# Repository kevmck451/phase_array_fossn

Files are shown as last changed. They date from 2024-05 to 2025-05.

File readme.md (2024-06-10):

# Forward Operations Security Sensor Network (FOSSN)

## Project Overview

What they want from us:
	- easily deployable networked sensor system is needed to provide automated security monitoring
	- develop concepts for a Forward Operations Sensor Network

The sensor system should 
	- detect encroaching personnel and vehicles (ground and aerial)
	- presence of chemical, biological, radiological, and nuclear (CBRN) materials
	- system of unattended sensors will communicate via a network
	- Autonomous algorithms will consolidate sensor inputs and provide summary notifications of activity within the area monitored to personnel in the FO unit

Results of this study:
	- a demonstration of several key technologies necessary for building an effective FOSSN 
	- a detailed plan for the full development of the FOSSN

Complementary sensors of acoustic

Unattended Ground Sensors (UGS)
Memphis has developed the means for implementing acoustic, magnetic, and hyperspectral sensors for UAS that can be translated to UGS sensing

The FOSSN team will translate these wide area coverage sensors into an UGS configuration and will demonstrate a VIS and LWIR capability for wide area coverage to include the detection and recognition of humans and vehicles.  The FOSSN team will also perform field experimentation to determine the performance of these systems in the range at which these systems effectively engage humans and military vehicles, including threat UAS.

The FOSSN team will also leverage existing phased array acoustic sensing to a UGS configuration

All sensors will be tied together leveraging Named Data Networking (NDN) and multi-hop ad hoc communications developed for the ARL program

Based on prior experience and input from task 3.1, research areas needed for the development of a complete and operationally effective system will be developed. For each area, recommendations regarding technical approaches will be made and a report produced. 

3.4.2 Phased Array Acoustic Sensor Research
	- The FOSSN team will develop a wide area coverage acoustic with at least a 180 degree FOV with resolution sufficient to localize a target direction when combined with other sensing modalities. This sensor will leverage technologies developed for the UAS based acoustic interrogator mission.
	- The FOSSN team will demonstrate the acoustic UGS systems in the field.  The system will be demonstrated in the field with a ground sensor coupled to a tabletop computer that can show the performance of the system.
	- The FOSSN team will determine the performance of the wide area acoustic system.  A theoretical performance will be provided as well as a field experiment/demonstration that provides the range at which aerial and ground vehicles can be detected and recognized.

The FOSSN team will develop an overall plan for developing a system that meets the needs of field artillery security. This plan will detail any needed technology development and the necessary resources to execute the plan. 

Test and Evaluation (T&E) Plan – Based on the results of laboratory and field evaluations and demonstrations, an overall T&E plan will be developed for a complete field artillery security system. 

# Repo Contents

## I. Beamform

## II. Circuit Boards

### 1. DE10_Shield

### 2. Mic_Antenna

## III. Documents

## IV. FPGA SoC Setup

1. Creating a NixOS for an FPGA SoC
2. Initial Build for SD Card Image
3. Initial Installation on DE10
4. Developing Application and Maintenance

### 1. FPGA Folder

- The Altera DE10 Nano uses Quartus to synthesize/place & route the HDL code to the FPGA 
- Quartus is only able to do this using an intel processor
- Nix is linux
- so in order to develop software on this device with Nix, a computer with intel processor and linux is needed

### 2. Nix
- Development Environment
- Package Management
- FPGA Interaction Tool Chain

### 3. Design

### 4. Docs

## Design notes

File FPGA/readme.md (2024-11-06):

# <u>Setup and Maintenance for the DE10-Nano</u>

**<u>First Time Setup Instructions</u>**
1. Programming Environment Setup
2. Building SD Card Image
3. First Connection to DE10-Nano

**<u>Developing and Maintenance</u>**
1. Updating OS Packages
2. Library update maintenance
3. Rebuilding software changes

---
# <u>First Time Setup Instructions</u>
- Building the necessary files for operating the DE10 Nano must be done with:
  - a pc with an intel processor running linux
  - Ubuntu is recommended, but other variants like lubuntu can work
  - lubuntu is lite ubuntu which is for computers with limited cpu ability
- This process was tested on a [Wo-We Mini PC](https://www.amazon.com/dp/B0CLD8JRWK?psc=1&ref=ppx_yo2ov_dt_b_product_details)
  - it worked but was very slow and needed special consideration with some aspects of the nix builds 
  - It's processor is an Intel Celeron N4020 CPU @ 1.1GHz x 2 (4GB RAM) running [lubuntu 24.04 64 bit](https://lubuntu.me/downloads/)
- It was also test with a [GMKtec Mini PC](https://www.amazon.com/gp/product/B0B75PT2RY/ref=ppx_yo_dt_b_search_asin_title?ie=UTF8&th=1)
  - processor is an Intel 11th Gen N5105 @ 3.4GHz x 4 (8GB RAM) running [Ubuntu 20.04.6](https://releases.ubuntu.com/focal/)

---
## <u>1. Programming Environment Setup</u>

### 1.1: Computer Requirements
- recommended minimum computer requirements
  - having two cores and 4GB memory with swap memory at 16GB is theoretically possible
  - four cores with 8GB memory and 16GB swap memory took 10+hrs to build for the first time

---
### 1.2: Installing Necessary Libraries
- htop: used to monitor computer during builds
```zsh
sudo apt install htop
```
- git: updating code repository after changes
```zsh
sudo apt install git
```
- wormhole: easily transfer files over the network without needing an IP
```zsh
sudo apt install magic-wormhole
```
- curl: used to install nix / copies files from a url
```zsh
sudo apt install curl
```
- nix: environment shells / NixOS builds / etc
```zsh
sudo apt install nixos
```
- ifconfig: used to see device's network information (specifically IP address)
```zsh
sudo apt install net-tools
```
- ssh: allows you to "login" to other computers and control them from the terminal
```zsh
sudo apt install openssh-server
```
- zstd: for decompressing .zst files
```zsh
sudo apt install zstd
```
- minicom: used to communicate with devices through UART
```zsh
sudo apt install minicom
```
- Sometimes, you might need appropriate permissions to access these devices
- You can change the permissions by adding your user to the dialout group
- kevmck would be replaced with your username
```zsh
sudo usermod -aG dialout kevmck
```
- program that tries to find modems on serials ports so get rid of it
```zsh
sudo apt purge modemmanager
```
This process is actually a perfect segway into NixOS in that in order to set up Ubuntu OS to do what you need.
This process has to be done every time a new computer is set up. That can be kind of cumbersome.
What if there was an OS that you could declare everything you need up front and then build/rebuild when changes are made.
Although Nix has many features, this is main advantage of using nix that you can declare everything you need
and you know that it will be built the same way everytime and will always work exactly the way it's suppose to

---
### 1.3: Installing Nix 
- [Nix Website](https://nixos.org/download/#nixos-iso)
- Browsing for Nix Packages [Package Search Website](https://search.nixos.org/packages?ref=itsfoss.com) 
- Multi-user installation for Linux
```zsh
sh <(curl -L https://nixos.org/nix/install) --daemon
```
- Adding the flake feature
- the folder might already exist
```zsh
sudo mkdir /etc/nixos
sudo nano /etc/nixos/nixos.conf
```
- Add this to the config file
- the first line is most important
- if there's something already there, delete it
~~~
# Nix Config File

# enable flake feature
experimental-features = nix-command flakes

# specifies which users are trusted by the Nix daemon
trusted-users = @root

# automatically optimize the store by deduplicating files
# performing other optimizations to reduce disk usage and improve performance
auto-optimise-store = true
~~~

---
### 1.4: Increasing Swap Memory
What is Swap Memory and why it's important
- check current swap memory size with htop or this;
```zsh
sudo swapon --show
```
- disable current swap file temporarily
```zsh
sudo swapoff /swapfile
```
- resize the swap file to 16GB
```zsh
sudo dd if=/dev/zero of=/swapfile bs=1M count=16384
```
- set the correct permissions
```zsh
sudo chmod 600 /swapfile
```
- setup the swap area
```zsh
sudo mkswap /swapfile
```
- enable the swap file
```zsh
sudo swapon /swapfile
```
- you should see the swap changing in htop but can also check with this:
```zsh
sudo swapon --show
```
- Edit the '/etc/fstab' file to ensure the swap file is used at boot
```zsh
sudo nano /etc/fstab
```
- add or update the following line to ensure it reads:
~~~
/swapfile none swap sw 0 0
~~~

---
## <u>2. Building SD Card Image</u>

### 2.1: Build SD Card Image for DE10
- This repo contains an already made NixOS system for the DE10
```zsh
git clone https://github.com/kevmck451/phase_array_fossn.git 
```
```zsh
cd phase_array_fossn/FPGA
```
- this only needs to be done once
- then updates can be run from the device itself with ```nix rebuild``` command

- run the command:
```zsh
nix build .#nixosConfigurations.de10-nano -L
```
- add the -j1 flag if using small cpu computers (1 job built at a time)
- -L is to see a verbose output as it builds
- this will take some time the first time (8+ hours potentially)
- there is no harm in stopping the build and restarting it
- it could potentially reduce memory if needed
- might run into 'lack of disk space' error
  - this might be due to tmp space not big enough
  - google remount /tmp with larger size
---

### 2.2: Create Bootable Drive
- this part could be done on any computer
- the ```nix build``` command from above makes a folder called "result"
- inside that folder is sd-image folder
- inside that is a .img.zst file
- use zstdcat & dd to decompress the image and write it to the SD card

1. Insert SD card into computer
2. Identify sd card's device name
   - not the mount point of the SD card, but the device name
```zsh
lsblk 
```
   - the name that corresponds with the mount point / SD card name
   - mine is 'mmcblk1'

3. Unmount the SD card (if it's mounted)
   - it wont hurt to do this if you're not sure
```zsh
sudo umount /dev/mmcblk1
```
4. Decompress and Write Image
   - *Warning:* incorrect use of ```dd``` commands could destroy your computer's internal disk, so use with care

```zsh
zstdcat result/sd-image/*.img.zst | sudo dd of=/dev/mmcblk1 bs=4M status=progress conv=fsync
```
- if you eject the sd card when it's done and reinsert it, it should say NixOS as the sd card name

---
## <u>3. First Connection to DE10-Nano</u>

### 3.1: Starting up the DE10
- put the SD card in the DE10
- set de10 mel switches to all 0 (up)
- connect to the de10 through the UART mini usb connector
- plug the power cable to the DE10

There are two ways we will connect to the DE10:
1. connection over UART 
2. connection via ssh with ethernet over usb 
    
---

#### 3.2: UART Connection on Linux
- plug in the mini-usb cable into the UART connector (by the ethernet port)
- the LEDs should light up immediately because it's getting power over the usb cable
  - even if the board is off
- start the UART connection
- most likely USB0, but maybe USB1
```zsh
minicom -D /dev/ttyUSB0 -b 115200
```
- once run, you should see start up of device
- to exit session: press control a, let go of both, press x

---

#### 3.3: SSH Connection
- plug in the micro-usb cable into the board
- connection to the internet is required
- SSH into FPGA
```zsh
ssh nixos@192.168.80.1
```
- save the address to your computer (optional)
```zsh
sudo nano /etc/hosts 
```
- add to the file
~~~
# DE10 Nano FPGA
192.168.80.1 fpga
~~~
- now you can ssh into it with this command
```zsh
ssh nixos@fpga 
```

#### 3.4: SSH Connection with MacBook
- this is done on the MacBook terminal
- get intel linux ip address and username
- Copy SSH key to connect without password
- replace kevmck with your username
- replace that IP address with your linux computer's
```zsh
ssh-copy-id kevmck@141.225.162.254
```
- SSH into intel linx comp
```zsh
ssh kevmck@141.225.162.254
```
- SSH into FPGA from MacBook with jumping
```zsh
ssh nixos@192.168.80.1 -J kevmck@141.225.162.254    
```

---
### 3.5 Test FPGA wavdump functionality
- on macbook, ssh into fpga with jumping (from 5.3)
- run the wavdump command with -f for fake mics
- run with -r for raw output, not convolved
```zsh
sudo wavdump -f -r fake_mic_test.wav
```
- once a few samples have been generated, press ctl c to stop

- copy the file to macbook for inspection with Audacity
```zsh
scp -J kevmck@141.225.162.254 nixos@192.168.80.1:/home/nixos/fake_mic_test.wav .
```
- from here, changes made to code will need to be rebuilt

---
# <u>Developing and Maintenance</u>
## <u>1. Updating OS Packages</u>

### 1.1: Adding Shell Libraries
- find packages in 'nixos/sd-image/default.nix'
- when changes are made, follow process in 3. Rebuilding Software Changes to implement

### 1.2: Adding Python Libraries

---
## <u>2. Library Update Maintenance</u>

---
## <u>3. Rebuilding Software Changes</u>

- if using MacBook to control headless Intel Linux PC then ssh into intel linux pc
```zsh
ssh kevmck@141.225.167.131
```
- from here you can either do this from the intel linux comp or ssh'd from macbook
- cd into FPGA folder with nix flake file
```zsh
cd Desktop/phase_array_fossn/FPGA
```
- update the changes that were made to the intel linux pc
```zsh
git pull
```
- cd into FPGA folder
- get inside a nix shell to rebuild any changes
```zsh
nix develop --profile profiles/dev
```
- note: if using a dash (nix-develop) nix would expect a default.nix file
  - not using the dash, signifies using a nix.flake file
- for significant changes, it's best use the boot flag
```zsh
nixos-rebuild --target-host nixos@192.168.80.1 --fast --use-remote-sudo --flake .#de10-nano boot -L 
```
- otherwise the switch command is fine
```zsh
nixos-rebuild --target-host nixos@192.168.80.1 --fast --use-remote-sudo --flake .#de10-nano switch -L 
```

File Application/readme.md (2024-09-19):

# App Info

## Powering On
- when the phased array is powered on, computer cannot be connected to it
- once booted, connect computer via ethernet and run Application.main

## Monitoring the FPGA and Pi during run
```zsh
ssh admin@192.168.1.1 
journalctl -fu temp-sensor-server
```

```zsh
ssh nixos@192.168.1.201
journalctl -fu start-mic-server
```

- if pi is plugged campus ethernet and wifi is connected on laptop
```zsh
ssh admin@pi-nix.uom.memphis.edu   
```

```zsh
sudo nano /etc/resolv.conf
```
~~~
nameserver 8.8.8.8
~~~

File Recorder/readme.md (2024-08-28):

# Controller

## Audio Receiver
- The `AudioReceiver` class is designed to collect RAW audio data from an FPGA server
- It connects to the server over a socket, receives audio data in chunks, and stores it in a queue for processing
- This implementation is intended to handle multi-channel audio data in real-time
- Connects to an FPGA server using a socket
- Receives audio data in real-time
- Supports multi-channel audio data
- Stores received audio data in a thread-safe queue
- Provides a method to retrieve audio data for processing

```zsh
journalctl -fu start-mic-server
```

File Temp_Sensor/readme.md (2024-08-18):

# Temp Sensor: BME280

## Physical Connection
- Using 4 pin 1/8" audio jack for connector (TRRS)
4: tip: 3.3V
3: ring 1: scl
2: ring 2: gnd
1: sleeve: sda

#### confirming the address  
```zsh
# nix environment 
nix-shell -p i2c-tools

# read buses
i2cdetect 0
i2cdetect 1
i2cdetect 2
i2cdetect 3
i2cdetect 4
```
- 3 was the only one with a single address at 76
~~~
     0  1  2  3  4  5  6  7  8  9  a  b  c  d  e  f
00:                         -- -- -- -- -- -- -- -- 
10: -- -- -- -- -- -- -- -- -- -- -- -- -- -- -- -- 
20: -- -- -- -- -- -- -- -- -- -- -- -- -- -- -- -- 
30: -- -- -- -- -- -- -- -- -- -- -- -- -- -- -- -- 
40: -- -- -- -- -- -- -- -- -- -- -- -- -- -- -- -- 
50: -- -- -- -- -- -- -- -- -- -- -- -- -- -- -- -- 
60: -- -- -- -- -- -- -- -- -- -- -- -- -- -- -- -- 
70: -- -- -- -- -- -- 76 --    
~~~

#### test script
- python console to run example script from [Github](https://projects.raspberrypi.org/en/projects/build-your-own-weather-station/2)

#### Get all libraries into nix so it can build them for access in scripts
https://github.com/rm-hull/bme280
https://github.com/rm-hull/bme280/tags

#### add script to automatic start up with Nix

- check output of print statements
```zsh
journalctl -fu temp-sensor
```
```zsh
journalctl -fu temp-sensor-server
```

#### gitpull 
```zsh
sudo -s
sudo nano /etc/resolv.conf
```
~~~
change nameserver = 8.8.8.8
~~~

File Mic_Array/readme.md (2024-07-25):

# Mic Array

2. mic_coordinates
3. time delays
   - directional cosines
   - speed of sound
   - calculate time delays
   - convert to sample delay
4. fir_filter
   - generate sinc function
   - window function
5. Convolution
6. Summation
7. Normalization

Beamforming Process:

## Microphone Array Grid:
 * Define the positions of the microphones in the array using an (x,y) coordinate system.
 * these grid coordinate are from the perspective of in front the array with (0,0) at the top left
 * the reference is from the center of the array

## Calculate Time Delays:
 * Use directional cosines to model the direction of arrival of the sound wave, assuming far-field conditions where the wavefronts are planar
 * For each microphone, calculate the time delay τi  based on the directional cosines and the positions of the microphones
 * This involves computing the path differences and converting them into time delays using the speed of sound
 * speed of sound changes depending on temperature
 * convert the time delay to sample delay by multiplying by sample rate
 * Since the calculated sample delays are not always integers, fractional delays need to be handled.
 * The most accurate way to implement fractional delays is by designing FIR filters that approximate these delays.

## Create FIR Filters:
 * For each microphone, create a sinc function centered at the delay di
 * The sinc function represents the ideal low-pass filter that will be used to create the FIR filter
 * set cutoff frequency higher than desired frequency range of interest
 * The sinc function sinc(t−di) where t is the time index and di is the delay.
 * Apply a window function (e.g., Hamming, Hann, blackman) to the sinc function to truncate it to a finite length and smooth the edges.
 * blackman provides better side lob suppression at the cost of main lobe resolution
 * increasing the number of taps can increase main lob resolution at the cost of computational complexity
 * The result is a set of FIR filter coefficients for each microphone.

## Convolution:
 * Convolve each microphone's input signal with its corresponding FIR filter coefficients.
 * Convolution is a process where the input signal is multiplied and summed with the FIR filter coefficients to produce a delayed output signal.

## Summation:
 * Sum the delayed signals from all microphones.
 * This summation aligns the signals from the desired direction (beamforming), enhancing them while attenuating signals from other directions.

## Normalization:
 * Bring values back into expected ranges

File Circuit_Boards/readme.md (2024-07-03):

# Circuit Board Information

---
## Using Mics with Antennas
- the mic symbol on the mic modules should be facing away from center when connected
- before soldering mic pins to modules, check that the INMP441 chip is correctly placed from factory
    - discard any that are not correctly aligned

---
## Ethernet Cable Configuration
- RJ45 Ethernet connectors and cabling are used to connect the microphone antennas to the fpga shield
- making the cables from scratch allowed for exact cable lengths
- the antennas were designed to optimize the configuration of the mic module pins
- in the initial testing phase, the standard TIA 568B coloring configuration was used
- this caused issues with certain data channels due to the twisted pair configuration
- the ethernet cables were reconfigured to fix this issue
- if you wanted to use standard ethernet cables, you will need to reroute the mic antenna pins
- and reassign the fpga shield pins as well

### Standard Ethernet Configuration
~~~
Twisted Pairs
- Orange Stripe: ws
- Orange: d3 <--- This channel is corrupted because of ws

- Green Stripe: d1
- Green: gnd

- Blue Stripe: d2
- Blue: pwr

- Brown Stripe: clk
- Brown: d4 <--- This channel is corrupted because of clk
~~~

### Custom Ethernet Configuration
~~~
Twisted Pairs
- Orange Stripe: ws
- Orange: pwr

- Green Stripe: d3
- Green: d1

- Blue Stripe: clk
- Blue: gnd

- Brown Stripe: d2
- Brown: d4
~~~

#### Top

| Orange Stripe | Green | Brown Stripe | Blue Stripe |
|---|---|---|---|

#### Bottom

| Green Stripe | Orange | Blue | Brown |
|---|---|---|---|

#### Left to Right
| ws  | d3  | d1  | pwr | d2  | gnd | clk | d4  |
|-----|-----|-----|-----|-----|-----|-----|-----|
| os  | gs  | g | o | brs | b | bs  | br  |

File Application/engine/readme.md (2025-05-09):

# Engine Pipeline

## Array
1. Array Configs: info specific to each array selected at runtime
2. AudioReceiver: connects to FPGA server to collect data
3. AudioStream: saves to data to disk and divides in user defined chunks for queue
4. AudioStreamSimulator: simulated stream from already collected array data

## Beamform
1. Beamform: facilities beamforming data from a given array
2. Mic_Coordinates: generates an arbitrary coordinate system for the array
3. Generate FIR Coeffs: time delays and FIR filters
4. Time Delays: calculate the time delays
5. FIR Filter: create the fir filter coefficients for each mic

## Filters
1. Processor: implements the processing pipeline for narrow band monitoring
2. High Pass: remove low frequencies below a cutoff
3. Down Sample: lower data size and low pass filter below cutoff(nyquist) / 2 
4. Normalize: min/max normalization - re-adjust data to fit inside the contain
5. Noise Reduction: possibility for noise reduction. not currently used

## Detectors
1. PCA Calculator: calculates the principal components from audio data using 'nperseg' and 'num'
2. Detectors: using pca data, a normal operation baseline is calculated and then new data is statistically compared for anomaly detection

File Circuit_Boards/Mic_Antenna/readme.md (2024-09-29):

# Mic Antenna Circuit Board in KiCad

## Front
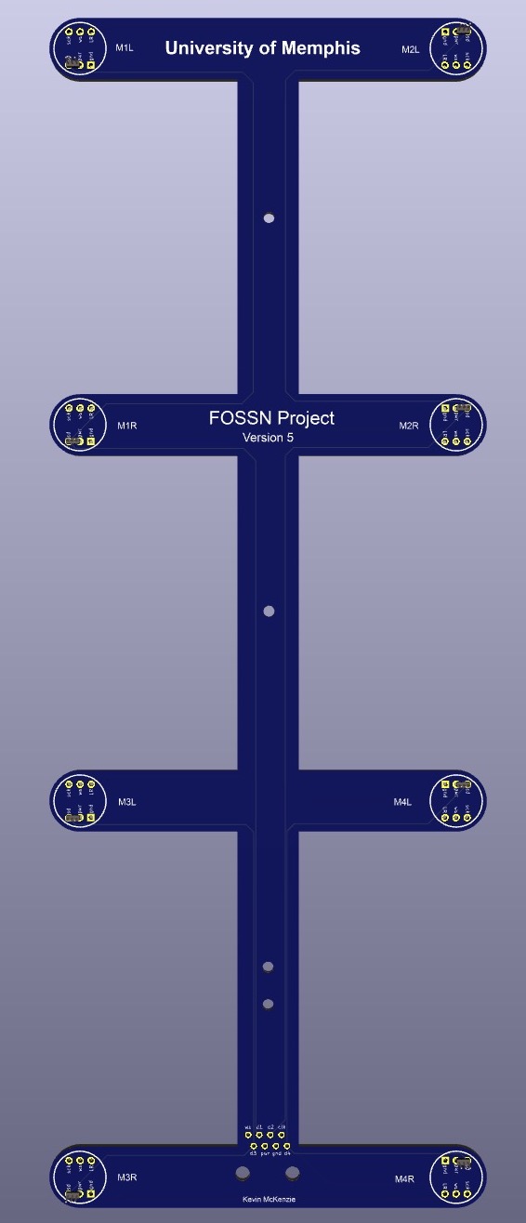
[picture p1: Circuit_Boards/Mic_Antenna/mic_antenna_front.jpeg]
Sheild Front


## Back
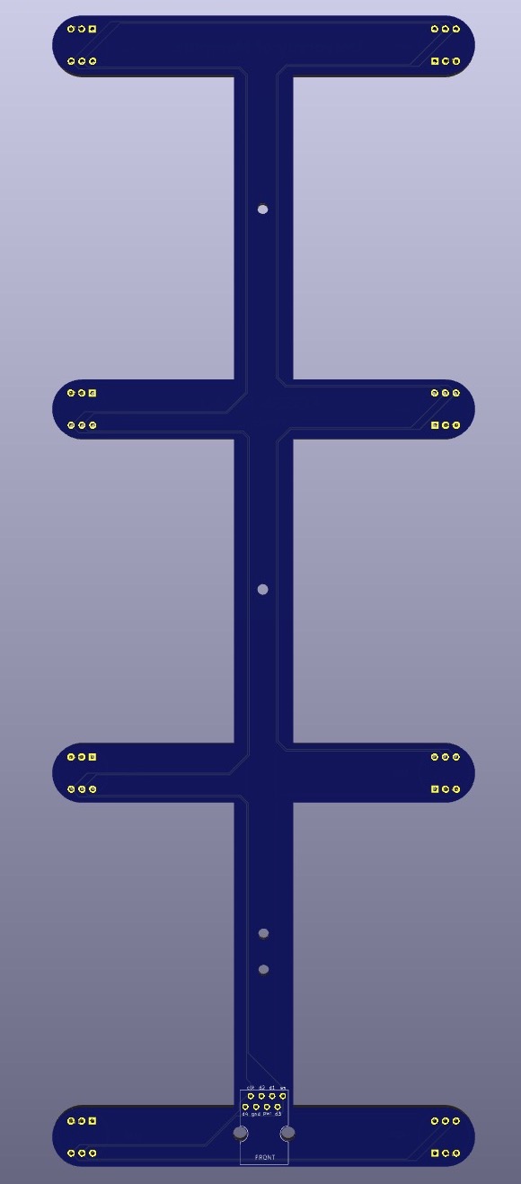
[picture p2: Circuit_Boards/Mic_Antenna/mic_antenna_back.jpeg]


## Exoskeleton
 - https://sendcutsend.com/
 - exoskeleton.stp
 - anodized aluminum (black)
 - these caused electrical interference in some mics
   - fixed by putting a sheet of printing paper in between
   - 2mm standoff screws used

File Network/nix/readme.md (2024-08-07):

# Loading and Building Networking NixOS for Raspberry Pi

## On the Raspberry Pi
- install a premade version of nix for pi
- [Tutorial](https://mtlynch.io/nixos-pi4/)

```zsh
sudo nix-channel --update
nix-env -iA nixos.git
```
- [YouTube Tutorial](https://www.youtube.com/watch?v=VIuPRL6Ucgk&list=WL&index=4)
```zsh
git clone https://github.com/kevmck451/phase_array_fossn.git
```
```zsh
cd phase_array_fossn/Network/nix/pi_sdcard
```
```zsh
sudo nix build --extra-experimental-features nix-command --extra-experimental-features flakes .#packages.aarch64-linux.sdcard
```

## On Mac
```zsh
scp nixos@192.168.0.137:~/phase_array_fossn/Network/nix/pi_sdcard/flake.lock ~/Downloads/
```
```zsh
scp -r nixos@192.168.0.137:~/phase_array_fossn/Network/nix/pi_sdcard/result ~/Downloads/
```
- remove sd card from pi and flash with new sd card image
```zsh
cd phase_array_fossn/Network/nix/pi_sdcard
```
```zsh
zstd -d result/sd-image/*.img.zst -o ~/Downloads/extracted_image.img        
```
- use belena etcher to flash to sd card
- put back in pi and start up
- find pi's ip address from router
- ssh into nixos pi
```zsh
ssh admin@192.168.0.137    
```
- enter password
- switch to root user
```zsh
sudo -s
```
```zsh
nix-channel --update
```
```zsh
nixos-generate-config
```
```zsh
nano /etc/nixos/configuration.nix
```
- everything is in the pi_config.nix file
```zsh
passwd admin
```
- choose password: nix
```zsh
nixos-rebuild switch
```
```zsh
arp -a   
```
- after disconnection from ssh, i had to unplug pi and plug back in
```zsh
arp -a   
```
- ssh into pi
```zsh
ssh admin@192.168.0.137
```
```zsh
git clone https://github.com/kevmck451/phase_array_fossn.git
```
```zsh
cd /home/admin/phase_array_fossn
git pull origin main
sudo cp /home/admin/phase_array_fossn/Network/nix/pi_config.nix /etc/nixos/configuration.nix
sudo nixos-rebuild switch
```

```zsh

```

```zsh

```

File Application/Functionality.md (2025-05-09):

# Application

1. Controller 
2. Engine 
3. GUI 
4. Temp Sensor

## Localization
    - Monitoring of each channel (current view)
    - heatmap of anomalies or energy

## Classification

## Human Operator
    - inject channel data into headphones (full range)
    - different listening modes
    - parameters to change volume or frequency

maybe have a speaker out in front of the array that can be triggered between tests for demo purposes

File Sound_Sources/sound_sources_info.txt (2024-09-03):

Sound Source: small speaker 2kHz sine wave
SPL (dB(C)): 88.0
Distance (meters): 2.0
Sound Power Level (SWL) in dB: 105.02
-----------------------------------------------------
Sound Source: small speaker semi truck idling
SPL (dB(C)): 78.0
Distance (meters): 2.0
Sound Power Level (SWL) in dB: 95.02
-----------------------------------------------------
Sound Source: tank idling in orlando
SPL (dB(C)): 88.0
Distance (meters): 10.0
Sound Power Level (SWL) in dB: 119.00
-----------------------------------------------------
Sound Source: tank idling in Eglin 2024
SPL (dB(C)): 94.0
Distance (meters): 5.0
Sound Power Level (SWL) in dB: 118.98
-----------------------------------------------------
Sound Source: hexacopter hovering
SPL (dB(C)): 98.0
Distance (meters): 1.0
Sound Power Level (SWL) in dB: 109.00
-----------------------------------------------------
Sound Source: angel uav propeller flying
SPL (dB(C)): 105.0
Distance (meters): 1.0
Sound Power Level (SWL) in dB: 116.00
-----------------------------------------------------
Sound Source: angel sound from speaker
SPL (dB(C)): 81.0
Distance (meters): 2.0
Sound Power Level (SWL) in dB: 98.02
-----------------------------------------------------
Sound Source: angel pink speaker
SPL (dB(C)): 90.0
Distance (meters): 2.0
Sound Power Level (SWL) in dB: 107.02
-----------------------------------------------------
Sound Source: semi idle pink speaker
SPL (dB(C)): 83.0
Distance (meters): 2.0
Sound Power Level (SWL) in dB: 100.02
-----------------------------------------------------
Sound Source: construction diesel vehicle full throttle
SPL (dB(C)): 98.0
Distance (meters): 12.0
Sound Power Level (SWL) in dB: 130.58
-----------------------------------------------------

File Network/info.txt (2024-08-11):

I want to create a NixOS configuration file for a Raspberry Pi that will essentially function as an access point for several purposes. The setup details are as follows:

1.	FPGA Device Connection:
    o	The FPGA device is connected to the Raspberry Pi over Ethernet over USB through the USB port.
    o	The FPGA’s IP address is 192.168.80.1.
    o	I need to access the FPGA from any computer connected to the Raspberry Pi’s wireless network.

2.	Wireless Network Configuration:
    o	The wireless network, created using a USB wireless network adapter attached to the Pi, should be called Phased_Array.
    o	The wireless network should have no password (open network).

3.	Internet Connectivity:
    o	The Ethernet port on the Raspberry Pi will be connected to my school’s internet for testing and updates.
    o	Any device connected to the Phased_Array network should also have access to the internet through the Ethernet port when it is connected.
    o	When out in the field, the Ethernet connection will not be available, and I will use the Pi's wireless network to access the FPGA's server.

4.	Home Network Configuration:
    o	The Raspberry Pi should also connect to my home network called KM 5 with the password XXXX for regular home use.

5.	Additional Requirements:
    o	Raspberry Pi is running NixOS.
    o	DHCP services for devices connected to the Phased_Array network.
    o	Enable NAT to share the Ethernet internet connection with the devices connected to the Phased_Array network when the Ethernet is connected.

I want to ssh into my raspberry pi through a wireless network

the wireless interface is wlp1s0u1u4

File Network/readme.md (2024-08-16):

# Networking Info for FOSSN Phased Array

# Wireless Implementation

- Starting with this [Website](https://nims11.wordpress.com/2012/04/27/hostapd-the-linux-way-to-create-virtual-wifi-access-point/)

## Hardware: Setting Up & Testing
- check wifi card support
```zsh
iw list | grep "Supported interface modes" -A 8
```
- looking for AP capabilities
~~~
	Supported interface modes:
		 * IBSS
		 * managed
		 * AP
		 * AP/VLAN
		 * monitor
		 * mesh point
	Band 1:
		Capabilities: 0x17e
--
	Supported interface modes:
		 * IBSS
		 * managed
		 * AP
		 * P2P-client
		 * P2P-GO
		 * P2P-device
	Band 1:
		Capabilities: 0x1020

~~~
- it's listed, so moving on
- install hostapd
```zsh
sudo apt-get update && sudo apt-get install hostapd
```
- configure test hostapd
```zsh
nano ~/hostapd-test.conf
```
~~~
#change wlan to your wireless device
interface=wlan1
driver=nl80211
ssid=test
channel=1
~~~
- Start 'test' network and confirm working 
```zsh
sudo hostapd ~/hostapd-test.conf
```

### Start Here if testing not needed
- here's the complete ```/etc/hostapd/hostapd.conf``` file
```zsh
sudo nano /etc/hostapd/hostapd.conf
```
~~~
# sets the wifi interface to use
interface=wlan1

# driver to use, nl80211 works in most cases
driver=nl80211

# sets the ssid of the virtual wifi access point
ssid=Acoustic_Camera

# sets the mode of wifi, depends upon the devices you will be using. It can be a,b,g,n. Not all cards support 'n'.
hw_mode=g

# sets the channel for your wifi
channel=6

# macaddr_acl sets options for mac address filtering. 0 means "accept unless in deny list"
macaddr_acl=0

# setting ignore_broadcast_ssid to 1 will disable the broadcasting of ssid
ignore_broadcast_ssid=0

# Sets authentication algorithm
# 1 - only open system authentication
# 2 - both open system authentication and shared key authentication
# auth_algs=1
##### Sets WPA and WPA2 authentication (remove this section if you don't need encryption)#####
# wpa option sets which wpa implementation to use
# 1 - wpa only
# 2 - wpa2 only
# 3 - both
# wpa=3
# sets wpa passphrase required by the clients to authenticate themselves on the network
# wpa_passphrase=KeePGuessinG
# sets wpa key management
# wpa_key_mgmt=WPA-PSK
# sets encryption used by WPA
# wpa_pairwise=TKIP
# sets encryption used by WPA2
# rsn_pairwise=CCMP
ctrl_interface=/var/run/hostapd
ctrl_interface_group=0

~~~

```zsh
sudo hostapd /etc/hostapd/hostapd.conf
```

## Setting Up DHCP Server

```zsh
sudo apt-get install dnsmasq

# confirm file exists
cat /etc/dnsmasq.conf

# save original as backup
sudo cp /etc/dnsmasq.conf /etc/dnsmasq.conf.backup

# delete file so we can replace it 
sudo rm /etc/dnsmasq.conf
```
- create new one
```zsh
sudo nano /etc/dnsmasq.conf
```

~~~
interface=wlan1
dhcp-range=10.0.0.2,10.0.0.20,24h
dhcp-option=option:router,10.0.0.1
dhcp-authoritative
~~~

## Sharing the Internet
```zsh
sudo sh -c "echo 1 > /proc/sys/net/ipv4/ip_forward"
```
```zsh
sudo iptables -t nat -A POSTROUTING -o wlan0 -j MASQUERADE
sudo iptables -A FORWARD -i wlan0 -o wlan1 -m state --state RELATED,ESTABLISHED -j ACCEPT
sudo iptables -A FORWARD -i wlan1 -o wlan0 -j ACCEPT

sudo iptables -t nat -A POSTROUTING -s 10.0.0.0/24 -o eth0 -j MASQUERADE
sudo iptables -A FORWARD -i eth0 -o wlan1 -m state --state RELATED,ESTABLISHED -j ACCEPT
sudo iptables -A FORWARD -i wlan1 -o eth0 -j ACCEPT

sudo iptables -t nat -A POSTROUTING -s 10.0.0.0/24 -o usb0 -j MASQUERADE
sudo iptables -A FORWARD -i wlan1 -o usb0 -j ACCEPT
sudo iptables -A FORWARD -i usb0 -o wlan1 -m state --state RELATED,ESTABLISHED -j ACCEPT
```
```zsh
sudo sh -c "iptables-save > /etc/iptables.ipv4.nat"
```

```zsh
sudo nano /etc/rc.local
```
- Add this line before exit 0:
~~~
iptables-restore < /etc/iptables.ipv4.nat
~~~

```zsh
sudo systemctl unmask hostapd
sudo systemctl enable hostapd
sudo systemctl start hostapd
sudo systemctl restart dnsmasq
```

```zsh
sudo reboot
```

## Start network on boot

- configure hostapd and dnsmasq to start at boot
```zsh
sudo systemctl enable hostapd; sudo systemctl enable dnsmasq
```

### Persist IP and Routing Configuration
```zsh
sudo nano /etc/dhcpcd.conf
```
- add this to the bottom of file
~~~
# Configuration for wlan1
interface wlan1
static ip_address=10.0.0.1/24
nohook wpa_supplicant

interface usb0
static ip_address=192.168.80.2/24

# Prefer wlan0 for default route
interface wlan0
static routers=192.168.0.1

# Add configuration to ignore routes for usb0
interface usb0
nogateway

# Set a lower metric for wlan0
interface wlan0
static ip_address=192.168.0.142/24
static routers=192.168.0.1
static domain_name_servers=192.168.0.1
metric 200
~~~
- add delay for start to ensure proper sync order
```zsh
sudo nano /etc/systemd/system/multi-user.target.wants/hostapd.service
```
- add this to bottom of service section
- change username as needed
~~~
ExecStartPre=/bin/sleep 15
ExecStartPost=/home/kevmck/setip.sh
~~~

```zsh
nano /home/kevmck/setip.sh
```
~~~
#!/bin/bash
ip addr add 10.0.0.1/24 dev wlan1
~~~
```zsh
chmod +x /home/kevmck/setip.sh
```

### Enable IP Forwarding and NAT Automatically
```zsh
sudo nano /etc/sysctl.conf
```
- uncomment line with this
~~~
net.ipv4.ip_forward=1
~~~
```zsh
sudo sysctl -p
sudo mkdir /etc/iptables
sudo iptables-save | sudo tee /etc/iptables/rules.v4 > /dev/null
sudo apt install iptables-persistent
sudo reboot
```

## Ensure compatability with FPGA ethernet over USB
- make sure fpga is plugged in so usb interface is up
```zsh
sudo ip addr add 192.168.80.2/24 dev usb0
sudo ip route del default via 192.168.0.1 dev wlan0
sudo ip route add default via 192.168.0.1 dev wlan0 metric 100
sudo ip route del default via 192.168.0.1 dev wlan0
sudo ip route del default via 192.168.80.1 dev usb0
sudo ip route add default via 192.168.0.1 dev wlan0 metric 100

```

- test if working
```zsh
ping 192.168.80.1
```
```zsh
ping google.com
```

### Add local host names
```zsh
sudo nano /etc/hosts
```
~~~
192.168.80.1    fpga
~~~

- make pi ip static
```zsh
sudo nano /etc/dhcpcd.conf 
```
~~~
interface eth0
static ip_address=10.0.0.13/24
static routers=10.0.0.1
static domain_name_servers=10.0.0.1
~~~

```zsh
# from macbook
ssh pi@papapi.local

# how to ssh into other devices
ssh nixos@fpga
ssh pi@acousticpi
```

pi ip on school: 141.225.163.221 or pi-nix

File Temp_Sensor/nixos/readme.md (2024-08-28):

# Loading and Building Networking NixOS for Raspberry Pi

## Initial Setup
- you will need to build nixos sd card image on a processor that the device will be running on
- for this, we will be using a raspberry pi to build
- so to start out we need to get any nixos working on the pi so we can build a custom sd_card image
- once you have an sd image built from a custom configuration.nix file you can 
  - then ssh into the device
  - download a git repo with your config files
  - rebuild the nixos in place without having to shutdown
  
### Steps for Initial Setup
-On the Raspberry Pi
- install a premade version of nix for pi
- [Tutorial](https://mtlynch.io/nixos-pi4/)

```zsh
sudo nixos-channel --update
nixos-env -iA nixos.git
```
- [YouTube Tutorial](https://www.youtube.com/watch?v=VIuPRL6Ucgk&list=WL&index=4)
```zsh
git clone https://github.com/kevmck451/phase_array_fossn.git
```
```zsh
cd phase_array_fossn/Network/nixos/sd-image
```
```zsh
sudo nixos build --extra-experimental-features nixos-command --extra-experimental-features flakes .#packages.aarch64-linux.sdcard
```

### On Mac
```zsh
scp nixos@192.168.0.137:~/phase_array_fossn/Network/nixos/sd-image/flake.lock ~/Downloads/
```
scp nixos@192.168.0.143:~/etc/nixos/hardware-configuration.nix ~/Downloads/
```zsh
scp -r nixos@192.168.0.137:~/phase_array_fossn/Network/nixos/sd-image/result ~/Downloads/
```
- remove sd card from pi and flash with new sd card image
```zsh
cd phase_array_fossn/Network/nixos/sd-image
```
```zsh
zstd -d result/sd-image/*.img.zst -o ~/Downloads/extracted_image.img        
```
- use belena etcher to flash to sd card
- put back in pi and start up
- find pi's ip address from router
- ssh into nixos pi
```zsh
ssh admin@192.168.0.137    
```
- enter password
- switch to root user
```zsh
sudo -s
```
```zsh
nixos-channel --update
```
```zsh
nixos-generate-config
```
```zsh
nano /etc/nixos/configuration.nix
```
- everything is in the pi_config.nix file
```zsh
passwd admin
```
- choose password: nix
```zsh
nixos-rebuild switch
```
```zsh
arp -a   
```
- after disconnection from ssh, i had to unplug pi and plug back in
```zsh
arp -a   
```
- ssh into pi
```zsh
ssh admin@192.168.0.137
```
```zsh
git clone https://github.com/kevmck451/phase_array_fossn.git
```
- move the file manually (optional)
```zsh
cd /home/admin/phase_array_fossn
git pull origin main
sudo cp /home/admin/phase_array_fossn/Network/nixos/configuration.nixos /etc/nixos/configuration.nix
sudo cp /home/admin/phase_array_fossn/Network/nixos/hardware-configuration.nix /etc/nixos/hardware-configuration.nix
sudo nixos-rebuild switch
```
- create a symlink to config file 
```zsh
sudo rm /etc/nixos/configuration.nix
sudo rm /etc/nixos/hardware-configuration.nix
sudo ln -s /home/admin/phase_array_fossn/Network/nixos/configuration.nix /etc/nixos/configuration.nix
sudo ln -s /home/admin/phase_array_fossn/Network/nixos/hardware-configuration.nix /etc/nixos/hardware-configuration.nix
```
- check for errors before installing
```zsh
sudo nixos-rebuild dry-run
```

```zsh
ssh admin@pi-nix.local  
```
- pi IP on school: 141.225.162.166
- pi IP at home: 192.168.0.137

- to connect to pi without ip
```zsh
ssh admin@pi-nix.uom.memphis.edu
```

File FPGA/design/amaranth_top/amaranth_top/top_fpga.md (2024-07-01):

# FGPA Top File
1. AudioAdapter Class
2. FPGATop Class
3. gen_build function

---
## Audio Adapter
- Transforms a 16-bit audio RAM bus into a 32-bit AXI3 bus
- handles AXI3 signaling for address writes and data writes, 
  - including burst mode and alignment of addresses
- includes a mechanism to split 16-bit audio data across 32-bit AXI bus words, 
  - also manages byte strobes 

---
## FPGA Top
- Establishes the top-level module for the FPGA setting up:
  - clocks and PLLs
  - GPIO resources, 
  - connections to the HPS (Hard Processor System) of the Cyclone V SoC
- Includes defining clock domains for microphone capture and convolution, 
  - wiring GPIOs for microphone data, and connecting audio RAM bus to the AXI3 interface. 
- It also integrates other necessary submodules such as the Convolver, PLLs, 
  - and CSR (Control and Status Register) bridge.
  
### Updating I/O Ports for FOSSN
- DE1-Nano user manual page 28 of 118
- we are using DE10-nano shield A from Circuit Boards
- which goes on GPIO 0 pins

### Antenna Mic Order / Data lines
perspective from front of mic antenna

| | |
|-----|-----|
| d1  | d2  |
| d3  | d4  |

| | |
|---|---|
| 1L (ch2) | 2L (ch4) |
| 1R (ch1) | 2R (ch3) |
| 3L (ch6) | 4L (ch8) |
| 3R (ch5) | 4R (ch7) |

### GPIO Pins
| Ant 1  | Ant 2  | Ant 3  | Ant 4  | Ant 5  | Ant 6  |
|---|---|---|---|---|---|
| d1: 13 | d1: 02 | d1: 16 | d1: 28 | d1: 39 | d1: 25 |
| d2: 15 | d2: 01 | d2: 14 | d2: 26 | d2: 40 | d2: 27 |
| d3: 07 | d3: 06 | d3: 20 | d3: 34 | d3: 35 | d3: 21 |
| d4: 19 | d4: 05 | d4: 08 | d4: 22 | d4: 36 | d4: 33 |

### Clk Pins & Index
| Ant | pins |
|-----|---|
| 1 | 17 |
| 2 | 03 |
| 3 | 10 |
| 4 | 24 |
| 5 | 38 |
| 6 | 31 |

### WS Pins & Index
| Ant | pins |
|-----|---|
| 1 | 09 |
| 2 | 04 |
| 3 | 18 |
| 4 | 32 |
| 5 | 37 |
| 6 | 23 |

### GPIO Pin List
| | | | |
|-----|---|-----|---|
| 01  | A2 d2  | 02  | A2 d1  |
| 03  | A2 clk | 04  | A2 ws  |
| 05  | A2 d4  | 06  | A2 d3  |
| 07  | A1 d3  | 08  | A3 d4  |
| 09  | A1 ws  | 10  | A3 clk |
| 13  | A1 d1  | 14  | A3 d2  |
| 15  | A1 d2  | 16  | A3 d1  |
| 17  | A1 clk | 18  | A3 ws  |
| 19  | A1 d4  | 20  | A3 d3  |
| 21  | A6 d3  | 22  | A4 d4  |
| 23  | A6 ws  | 24  | A4 clk |
| 25  | A6 d1  | 26  | A4 d2  |
| 27  | A6 d2  | 28  | A4 d1  |
| 31  | A6 clk | 32  | A4 ws  |
| 33  | A6 d4  | 34  | A4 d3  |
| 35  | A5 d3  | 36  | A5 d4  |
| 37  | A5 ws  | 38  | A5 clk |
| 39  | A5 d1  | 40  | A5 d2  |

---
## Generator Build Files
The gen_build function prepares build constraints and settings for the FPGA compilation process 
using the DE10-Nano platform, generating the required files for FPGA synthesis and implementation.

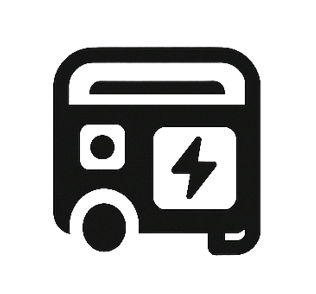
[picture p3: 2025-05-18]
Application/docs/generator.png

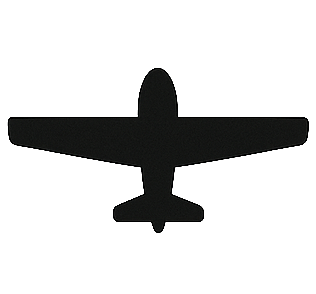
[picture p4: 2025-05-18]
Application/docs/plane.png

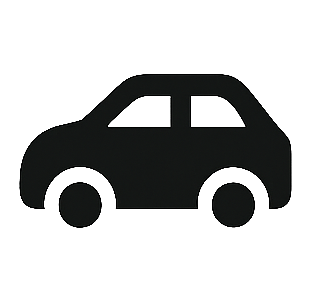
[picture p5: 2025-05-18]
Application/docs/car.png

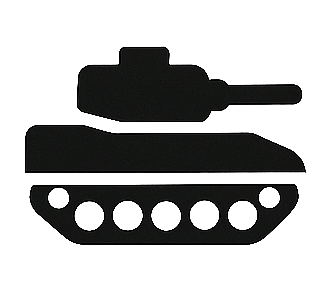
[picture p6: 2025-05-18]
Application/docs/tank.png

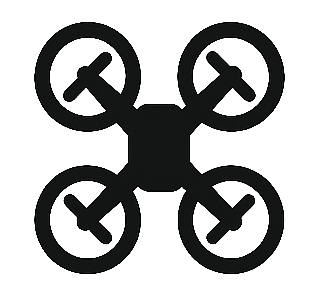
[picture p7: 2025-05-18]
Application/docs/drone.png

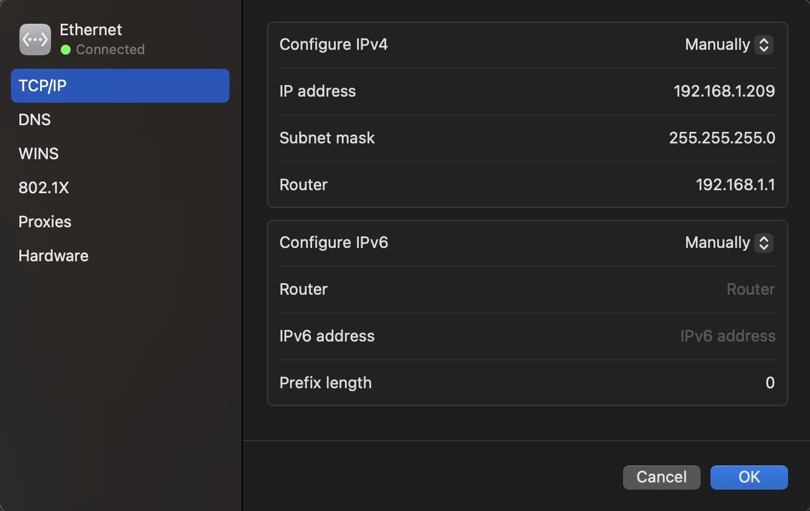
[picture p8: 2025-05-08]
Network/Screenshot 2025-02-25 at 3.33.26 PM.JPG

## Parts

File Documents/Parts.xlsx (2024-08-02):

FOSSN Acoustic Purchase List |  | Total: | $1030.32
Item | Tech Name | Price | Quantity | Total | Links
FPGA | DE10-Nano Kit | $190.00 | 1 | $190.00 | https://www.terasic.com.tw/cgi-bin/page/archive.pl?Language=English&CategoryNo=165&No=1046#contents
SD Card | SanDisk 256GB Micro SD Card | $25.87 | 1 | $25.87 | https://www.amazon.com/SanDisk-256GB-Extreme-MicroSDXC-Memory/dp/B082WNC4NK/ref=sr_1_18
Microphones | INMP441 Omnidirectional Microphone Module | $1.38 | 50 | $69.00 | https://www.aliexpress.com/i/3256801419282454.html?gatewayAdapt=4itemAdapt
Mic Power | 3.3V Linear Regulator | $6.99 | 1 | $6.99 | https://www.amazon.com/WWZMDiB-AMS1117-3-3-Converter-4-75-12V-Step-Down/dp/B0BD5BMXBK | https://www.amazon.com/dp/B0C1C64R8S?psc=1&ref=ppx_yo2ov_dt_b_product_details
Mic Socket | 6 Pin IC Socket | $7.99 | 1 | $7.99 | https://www.amazon.com/dp/B0BNV2GTMF?ref=ppx_yo2ov_dt_b_product_details&th=1
Jacks | RJ45 Modular Jack (30 pack) | $9.24 | 1 | $9.24 | https://www.amazon.com/dp/B07CWJZSPC?psc=1&ref=ppx_yo2ov_dt_b_product_details
Connectors | RJ45 Ethernet Connectors (50 pack) | $9.99 | 1 | $9.99 | https://www.amazon.com/CableCreation-100-PACK-Connector-Connectors-Transparent/dp/B01K9Z4FT2
Tripod | 74" Heavy Duty Tripod for Cameras | $33.99 | 1 | $33.99 | https://www.amazon.com/CAMBOFOTO-Camera-Tripod-Porfessional-Mirrorless-Camcorder/dp/B0C8LXL2Y4
Tripod Connector | Mic Screw Dapter with Bottom Pedestal | $10.90 | 1 | $10.90 | https://www.amazon.com/gp/product/B07Z5ZYVGC/ref=ppx_yo_dt_b_asin_title_o00_s00?ie=UTF8&psc=1
Antenna Base | Braided Carbon Fiber Square Tubing (1x1x48) | $91.75 | 1 | $91.75 | https://dragonplate.com/braided-carbon-fiber-square-tubing-1-x-1-x-48
Battery | Portable Power Bank 50000mAh 30W | $49.99 | 1 | $49.99 | https://www.amazon.com/Portable-Charger-Power-Bank-50000mAh-Powerbank-Charging-External/dp/B0C147N71M
Mic Antenna Circuit Board | JLCPB Order for Mic Antenna Circuit Board | $3.00 | 10 | $30.00
FPGA Shield Circuit Board | JLCPB Order for DE10-Nano Kit Shield | $3.00 | 1 | $3.00
FPGA Board Pin Extenders | 2x20 Etra Tall Femaile Pin Header | $9.99 | 1 | $9.99 | https://www.amazon.com/dp/B084Q4W1PW?psc=1&smid=A12R7FMO56ISX4&ref_=chk_typ_imgToDp
Cabling | Cat6 Ethernet Patch Cable 6 ft (10 Pack) | $16.00 | 1 | $16.00 | https://www.amazon.com/Lysymixs-Ethernet-Centers-Network-Enterprise/dp/B0CY1PNCDY/ref=sr_1_12_sspa
Battery Cable | USB-C Male to DC 5.5X2.5mm Male Power Jack | $7.00 | 1 | $7.00 | https://www.amazon.com/dp/B07PT9SXL8?smid=A38M7NHUQS24NM&ref_=chk_typ_imgToDp&th=1
Wind Foam / Muff | Furry Windscreen & Foam for Lavalier Lapel Mic | $9.00 | 10 | $90.00 | https://www.amazon.com/gp/product/B0B2D836LY/ref=ppx_yo_dt_b_search_asin_title?ie=UTF8&psc=1
Tripod Bag |  | $12.00 | 1 | $12.00 | https://www.amazon.com/gp/product/B0CW3BZK58/ref=ppx_yo_dt_b_asin_title_o00_s01?ie=UTF8&th=1
Cable Ties |  | $6.00 | 1 | $6.00 | https://www.amazon.com/dp/B08V8NK5TN?ref=ppx_yo2ov_dt_b_product_details&th=1
Ethernet Cable Boots |  | $9.00 | 1 | $9.00 | https://www.amazon.com/dp/B07G237Z5M?psc=1&ref=ppx_yo2ov_dt_b_product_details
Tripod Bag |  | $10.00 | 1 | $10.00 | https://www.amazon.com/dp/B0CW3BZK58?ref=ppx_yo2ov_dt_b_product_details&th=1
Wireless Interface |  | $27.99 | 1 | $27.99 | https://www.amazon.com/Panda-Wireless-PAU0B-Adapter-Antenna/dp/B08NPX2X4Z/ref=asc_df_B08NPX2X4Z/
FPGA Enclosure |  | $75.41 | 1 | $75.41 | https://www.amazon.com/Hilitand-Terasic-DE10‑Nano-Accessories-Assemble/dp/B09M8QCXFQ
Pi Enclosure |  | $9.99 | 1 | $9.99 | https://www.amazon.com/Dorhea-Raspberry-Supporting-Installation-Heatsinks/dp/B07JBB9QSB/ref=sr_1_40
USB Extender |  | $6.29 | 1 | $6.29 | https://www.amazon.com/LORDTRONICS-Extender-Transfer-Charging-Playstation/dp/B0D7F6DF2T
Pi & Cam Power Cables |  | $9.99 | 1 | $9.99 | https://www.amazon.com/Cable-Matters-Extreme-Flexible-Charging/dp/B0CLZ93MGD/ref=sr_1_1
FPGA Power Cable |  | $5.39 | 1 | $5.39 | https://www.amazon.com/TENINYU-5-5x2-5mm-Barrel-Ampere-Positive/dp/B079ZY3MQB/ref=sr_1_1
Temp Sensor |  | $36.98 | 1 | $36.98 | https://www.amazon.com/Taidacent-Temperature-Humidity-Atmospheric-Barometric/dp/B08Y5KZSR2
Pi Mount |  | $14.84 | 1 | $14.84 | https://www.amazon.com/SmallRig-Adapter-Monitor-Insta360-1138/dp/B00DJ5XH4O/ref=sr_1_5
FPGA Mount |  | $21.24 | 1 | $21.24 | https://www.amazon.com/Neewer-Photography-Reflector-Motorcycle-Accessories/dp/B0CK28KNS7
Raspberry Pi | Raspbery Pi 4 Model B 2019 Quad Core 64bit | $61.75 | 2 | $123.50 | https://www.amazon.com/Raspberry-Model-2019-Quad-Bluetooth/dp/B07TC2BK1X

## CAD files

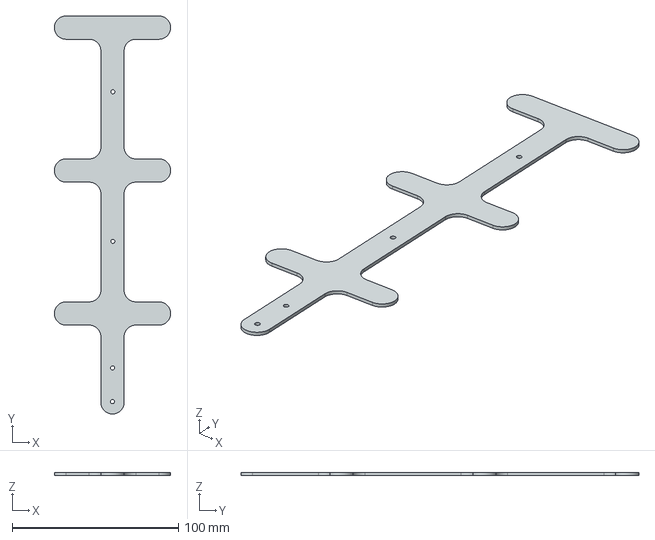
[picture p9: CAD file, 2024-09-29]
Circuit_Boards/Mic_Antenna/exoskeleton.stp
70.0 x 239.5 x 1.60 mm

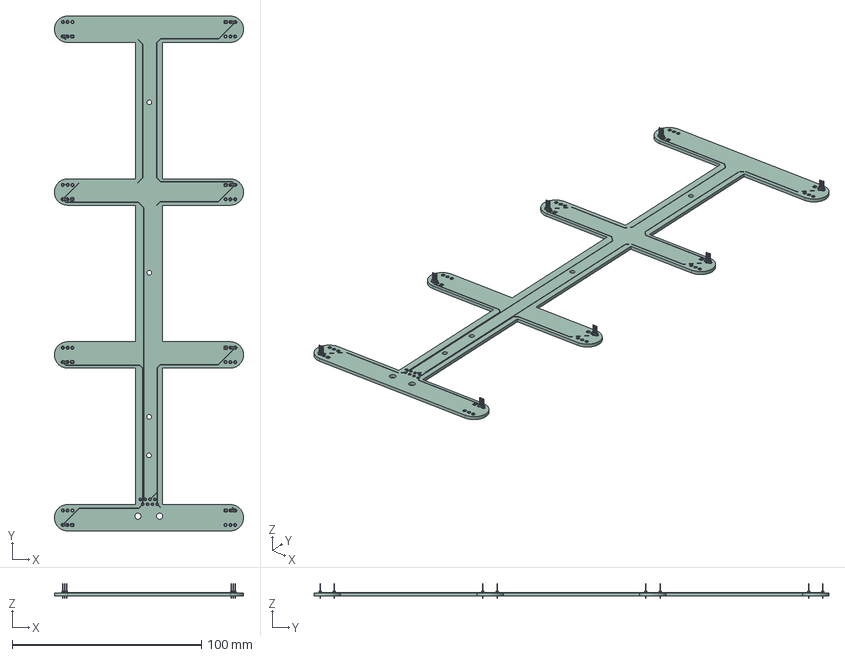
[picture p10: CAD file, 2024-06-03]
Circuit_Boards/Mic_Antenna/mic_antenna_circuit.step
99.9 x 272.0 x 7.80 mm
PinHeader_1x03_P100mm_Vertical x 8
mic_array_circuit_track_1
mic_array_circuit_track_2
mic_array_circuit_track_3
mic_array_circuit_track_4
mic_array_circuit_track_5
mic_array_circuit_track_6
mic_array_circuit_track_7
mic_array_circuit_track_8
mic_array_circuit_track_9
mic_array_circuit_track_10
mic_array_circuit_track_11
mic_array_circuit_track_12
mic_array_circuit_track_13
mic_array_circuit_track_14
mic_array_circuit_track_15
mic_array_circuit_track_16
mic_array_circuit_track_17
mic_array_circuit_track_18
mic_array_circuit_track_19
mic_array_circuit_track_20
mic_array_circuit_track_21
mic_array_circuit_track_22
mic_array_circuit_track_23
mic_array_circuit_track_24
mic_array_circuit_track_25
mic_array_circuit_track_26
mic_array_circuit_track_27
mic_array_circuit_track_28
mic_array_circuit_track_29
mic_array_circuit_track_30
mic_array_circuit_track_31
mic_array_circuit_track_32
mic_array_circuit_track_33
mic_array_circuit_track_34
mic_array_circuit_track_35
mic_array_circuit_track_36
mic_array_circuit_track_37
mic_array_circuit_track_38
mic_array_circuit_track_39
mic_array_circuit_track_40
mic_array_circuit_track_41
mic_array_circuit_track_42
mic_array_circuit_track_43
mic_array_circuit_track_44
mic_array_circuit_track_45
mic_array_circuit_track_46
mic_array_circuit_track_47
mic_array_circuit_track_48
mic_array_circuit_track_49
mic_array_circuit_track_50
mic_array_circuit_track_51
mic_array_circuit_track_52
mic_array_circuit_track_53
mic_array_circuit_track_54
mic_array_circuit_track_55
mic_array_circuit_track_56
mic_array_circuit_track_57
mic_array_circuit_track_58
mic_array_circuit_track_59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

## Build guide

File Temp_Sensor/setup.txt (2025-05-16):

408  sudo su
  409  i2cdetect
  410  i2cdetect /dev/i2c-0
  411  i2cdetect i2c-0
  412  i2cdetect 0
  413  sudo i2cdetect 0
  414  sudo i2cdetect 1
  415  sudo i2cdetect 2
  416  sudo i2cdetect 3
  417  sudo i2cdetect 4
  418  sudo i2cdetect 1
  419  sudo i2cdetect 1
  420  sudo i2cdetect 1
  421  sudo i2cdetect 2
  422  lsmod | grep i2c
  423  sudo i2cdetect 2
  424  sudo i2cdetect 2
  425  sudo i2cdetect 3
  426  sudo i2cdetect 3
  427  exit
  428  sudo python3
  429  ls
  430  wget https://github.com/rm-hull/bme280/archive/refs/heads/master.tar.gz
  431  curl https://github.com/rm-hull/bme280/archive/refs/heads/master.tar.gz
  432  ls
  433  curl https://github.com/rm-hull/bme280/archive/refs/heads/master.tar.gz -O out.tar.gz
  434  curl -o out.tar.gz https://github.com/rm-hull/bme280/archive/refs/heads/master.tar.gz
  435  ls
  436  ls -alh
  437  curl https://github.com/rm-hull/bme280/archive/refs/heads/master.tar.gz > out.tar.gz
  438  ls
  439  ls -alh
  440  curl https://github.com/rm-hull/bme280/archive/refs/heads/master.zip > out.tar.gz
  441  git clone https://github.com/rm-hull/bme280
  442  ls
  443  cd bme280/
  444  ls
  445  python3
  446  sudo python3
  447  exit
  448  sudo python3
  449  ls
  450  cd bme280/
  451  sudo python3
  452  cd
  453  edxit
  454  exit
  455  wormhole-william send a_file
  456  git pull
  457  exit
  458  ls /dev
  459  ls
  460  cat /proc/device-tree/soc/usb@7e980000/name
  461  cat /proc/device-tree/soc/usb@7e980000/compatible
  462  cat /proc/device-tree/soc/i2c@7e205000/compatible
  463  cat /proc/device-tree/soc/i2c@7e205000/pinctrl-
  464  cat /proc/device-tree/soc/i2c@7e205000/pinctrl-names
  465  nix-shell -p i2c-utils
  466  nix-shell -p i2cutils
  467  nix-shell -p i2c-tools
  468  nix-shell -p i2c-tools -p 'python3.withPackages (p: [ p.smbus ])'
  469  nix-shell -p i2c-tools -p 'python3.withPackages (p: [ p.smbus2 ])'
  470  nix-shell -p i2c-tools -p 'python3.withPackages (p: [ p.smbus2 p.pytz ])'
  471  ls
  472  rm -r bme280/ master.tar.gz out.tar.gz
  473  rm -rf bme280/ master.tar.gz out.tar.gz
  474  sudo rm -rf bme280/ master.tar.gz out.tar.gz
  475  python3
  476  ls
  477  cd phase_array_fossn/
  478  git pull
  479  history | grep switch
  480  sudo nixos-rebuild switch
  481  git pull
  482  sudo nixos-rebuild switch
  483  git pull
  484  sudo nixos-rebuild switch
  485  git pull
  486  sudo nixos-rebuild switch
  487  sudo nixos-rebuild switch > a_file 2>&1
  488  nix-shell -p wormhole-william
  489  sudo nixos-rebuild switch
  490  git pull
  491  sudo nixos-rebuild switch
  492  python3
  493  python3 Temp_Sensor/temp_sensor_server.py
  494  ls -alh /dev/i2c-3
  495  sudo udevadm trigger
  496  ls -alh /dev/i2c-3
  497  reboot
  498  sudo reboot
  499  journalctl -fu temp-sensor

23.11.7870.205fd4226592

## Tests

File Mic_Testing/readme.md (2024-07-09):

# Microphone Testing

- to test microphones, module sockets were soldered to an extra mic antenna (sockets in part list in docs)
- this mic antenna was also labeled as to not mix up the order of channels when testing

| | |
|---|---|
| 1L (ch2) | 2L (ch4) |
| 1R (ch1) | 2R (ch3) |
| 3L (ch6) | 4L (ch8) |
| 3R (ch5) | 4R (ch7) |

- testing the sensitivity of each mic ensures that all mics that are "hard wired" to the antennas are all in the same range
- a [REED R8090 Sound Level Calibrator](https://www.amazon.com/Instruments-R8090-Calibrator-Diameter-Microphones/dp/B008S0OVR2/) was used for our testing

## Testing Process
- start FPGA server running in raw mode at gain level 10
```zsh
sudo server -r -g 10 -c 8
```
- all mics were tested and results recorded in the MasterMicTest.csv in a quiet room
- using this data, the rms range variable in ```TestMics.py``` was selected for pass / fail thresholds
- it would be recommended to do this process yourself if your conditions are significantly different

### Testing
- run the ```TestMics.py``` script
- slide the calibrator to 94dB setting
- place calibrator on top of mic so that mic is securely in the opening
  - the fit should be almost exact so make sure calibrator is not angled and perfect level/centered on mic
  - small variation in calibrator placement could change the results so try to be consistent
- once you feel the calibrator is correctly positioned, press enter where ever the script is being run
- the script will collect 2 seconds worth of data and calculate the RMS value
- mics that are within the desired range will receive a PASS and other a fail
- once you have the number of mics needed for your array at the desired sensitivity, testing is complete
- the other mics are still good obviously so maybe save them for another project

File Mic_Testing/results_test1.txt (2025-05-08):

Enter Mic Number & press 'Enter' to test mic 1: 60
Testing mic 1
Mic 1 RMS value: 0.3185
Mic 1 Peak value: 0.67871

Mic 1: +++++++ PASSED +++++++

Enter Mic Number & press 'Enter' to test mic 2: 53
Testing mic 2
Mic 2 RMS value: 0.32118
Mic 2 Peak value: 0.67136

Mic 2: ------- FAILED -------

Enter Mic Number & press 'Enter' to test mic 3: 23
Testing mic 3
Mic 3 RMS value: 0.27022
Mic 3 Peak value: 0.75284

Mic 3: +++++++ PASSED +++++++

Enter Mic Number & press 'Enter' to test mic 4: 49
Testing mic 4
Mic 4 RMS value: 0.29756
Mic 4 Peak value: 0.67899

Mic 4: +++++++ PASSED +++++++

Enter Mic Number & press 'Enter' to test mic 5: 47
Testing mic 5
Mic 5 RMS value: 0.29206
Mic 5 Peak value: 0.63147

Mic 5: +++++++ PASSED +++++++

Enter Mic Number & press 'Enter' to test mic 6: 59
Testing mic 6
Mic 6 RMS value: 0.23177
Mic 6 Peak value: 0.52496

Mic 6: ------- FAILED -------

Enter Mic Number & press 'Enter' to test mic 7: 42
Testing mic 7
Mic 7 RMS value: 0.29907
Mic 7 Peak value: 0.70834

Mic 7: +++++++ PASSED +++++++

Enter Mic Number & press 'Enter' to test mic 8: 51
Testing mic 8
Mic 8 RMS value: 0.27661
Mic 8 Peak value: 0.62933

Mic 8: +++++++ PASSED +++++++

Enter Mic Number & press 'Enter' to test mic 1: 61
Testing mic 1
Mic 1 RMS value: 0.31569
Mic 1 Peak value: 0.65967

Mic 1: +++++++ PASSED +++++++

Enter Mic Number & press 'Enter' to test mic 2: 38
Testing mic 2
Mic 2 RMS value: 0.28749
Mic 2 Peak value: 0.63348

Mic 2: +++++++ PASSED +++++++

Enter Mic Number & press 'Enter' to test mic 3: 55
Testing mic 3
Mic 3 RMS value: 0.35095
Mic 3 Peak value: 0.72604

Mic 3: ------- FAILED -------

Enter Mic Number & press 'Enter' to test mic 4: 21
Testing mic 4
Mic 4 RMS value: 0.34016
Mic 4 Peak value: 0.70981

Mic 4: ------- FAILED -------

Enter Mic Number & press 'Enter' to test mic 5: 58
Testing mic 5
Mic 5 RMS value: 0.2633
Mic 5 Peak value: 0.56183

Mic 5: +++++++ PASSED +++++++

Enter Mic Number & press 'Enter' to test mic 6: 65
Testing mic 6
Mic 6 RMS value: 0.31367
Mic 6 Peak value: 0.6622

Mic 6: +++++++ PASSED +++++++

Enter Mic Number & press 'Enter' to test mic 7: 44
Testing mic 7
Mic 7 RMS value: 0.31848
Mic 7 Peak value: 0.65149

Mic 7: +++++++ PASSED +++++++

Enter Mic Number & press 'Enter' to test mic 8: 25
Testing mic 8
Mic 8 RMS value: 0.26488
Mic 8 Peak value: 0.59198

Mic 8: +++++++ PASSED +++++++

Enter Mic Number & press 'Enter' to test mic 1: 43
Testing mic 1
Mic 1 RMS value: 0.34946
Mic 1 Peak value: 0.84

Mic 1: ------- FAILED -------

Enter Mic Number & press 'Enter' to test mic 2: 20
Testing mic 2
Mic 2 RMS value: 0.28108
Mic 2 Peak value: 0.60083

Mic 2: +++++++ PASSED +++++++

Enter Mic Number & press 'Enter' to test mic 3: 48
Testing mic 3
Mic 3 RMS value: 0.17708
Mic 3 Peak value: 0.49088

Mic 3: ------- FAILED -------

Enter Mic Number & press 'Enter' to test mic 4: 13
Testing mic 4
Mic 4 RMS value: 0.24467
Mic 4 Peak value: 0.53015

Mic 4: ------- FAILED -------

Enter Mic Number & press 'Enter' to test mic 5: 4
Testing mic 5
Mic 5 RMS value: 0.27863
Mic 5 Peak value: 0.57193

Mic 5: +++++++ PASSED +++++++

Enter Mic Number & press 'Enter' to test mic 6: 5
Testing mic 6
Mic 6 RMS value: 0.28536
Mic 6 Peak value: 0.6076

Mic 6: +++++++ PASSED +++++++

Enter Mic Number & press 'Enter' to test mic 7: 152
Testing mic 7
Mic 7 RMS value: 0.28828
Mic 7 Peak value: 0.6105

Mic 7: +++++++ PASSED +++++++

Enter Mic Number & press 'Enter' to test mic 8: 56
Testing mic 8
Mic 8 RMS value: 0.26731
Mic 8 Peak value: 0.56213

Mic 8: +++++++ PASSED +++++++

Enter Mic Number & press 'Enter' to test mic 1: 26
Testing mic 1
Mic 1 RMS value: 0.26358
Mic 1 Peak value: 0.61288

Mic 1: +++++++ PASSED +++++++

Enter Mic Number & press 'Enter' to test mic 2: 7
Testing mic 2
Mic 2 RMS value: 0.26876
Mic 2 Peak value: 0.61987

Mic 2: +++++++ PASSED +++++++

Enter Mic Number & press 'Enter' to test mic 3: 3
Testing mic 3
Mic 3 RMS value: 0.24069
Mic 3 Peak value: 0.52258

Mic 3: ------- FAILED -------

Enter Mic Number & press 'Enter' to test mic 4: 1
Testing mic 4
Mic 4 RMS value: 0.22421
Mic 4 Peak value: 0.63846

Mic 4: ------- FAILED -------

Enter Mic Number & press 'Enter' to test mic 5: 17
Testing mic 5
Mic 5 RMS value: 0.2847
Mic 5 Peak value: 0.65436

Mic 5: +++++++ PASSED +++++++

Enter Mic Number & press 'Enter' to test mic 6: 45
Testing mic 6
Mic 6 RMS value: 0.29279
Mic 6 Peak value: 0.62912

Mic 6: +++++++ PASSED +++++++

Enter Mic Number & press 'Enter' to test mic 7: 62
Testing mic 7
Mic 7 RMS value: 0.34903
Mic 7 Peak value: 0.80042

Mic 7: ------- FAILED -------

Enter Mic Number & press 'Enter' to test mic 8: 28
Testing mic 8
Mic 8 RMS value: 0.24394
Mic 8 Peak value: 0.67627

Mic 8: ------- FAILED -------

Enter Mic Number & press 'Enter' to test mic 1: 11
Testing mic 1
Mic 1 RMS value: 0.27168
Mic 1 Peak value: 0.57196

Mic 1: +++++++ PASSED +++++++

Enter Mic Number & press 'Enter' to test mic 2: 37
Testing mic 2
Mic 2 RMS value: 0.25045
Mic 2 Peak value: 0.54388

Mic 2: ------- FAILED -------

Enter Mic Number & press 'Enter' to test mic 3: 12
Testing mic 3
Mic 3 RMS value: 0.32259
Mic 3 Peak value: 0.77188

Mic 3: ------- FAILED -------

Enter Mic Number & press 'Enter' to test mic 4: 52
Testing mic 4
Mic 4 RMS value: 0.36733
Mic 4 Peak value: 0.75745

Mic 4: ------- FAILED -------

Enter Mic Number & press 'Enter' to test mic 5: 9
Testing mic 5
Mic 5 RMS value: 0.33212
Mic 5 Peak value: 0.70111

Mic 5: ------- FAILED -------

Enter Mic Number & press 'Enter' to test mic 6: 6
Testing mic 6
Mic 6 RMS value: 0.27868
Mic 6 Peak value: 0.5856

Mic 6: +++++++ PASSED +++++++

Enter Mic Number & press 'Enter' to test mic 7: 33
Testing mic 7
Mic 7 RMS value: 0.35364
Mic 7 Peak value: 0.73132

Mic 7: ------- FAILED -------

Enter Mic Number & press 'Enter' to test mic 8: 34
Testing mic 8
Mic 8 RMS value: 0.27876
Mic 8 Peak value: 0.5946

Mic 8: +++++++ PASSED +++++++

Enter Mic Number & press 'Enter' to test mic 1: 57
Testing mic 1
Mic 1 RMS value: 0.25448
Mic 1 Peak value: 0.52783

Mic 1: +++++++ PASSED +++++++

Enter Mic Number & press 'Enter' to test mic 2: 14
Testing mic 2
Mic 2 RMS value: 0.28608
Mic 2 Peak value: 0.61737

Mic 2: +++++++ PASSED +++++++

Enter Mic Number & press 'Enter' to test mic 3: 8
Testing mic 3
Mic 3 RMS value: 0.29352
Mic 3 Peak value: 0.60944

Mic 3: +++++++ PASSED +++++++

Enter Mic Number & press 'Enter' to test mic 4: 27
Testing mic 4
Mic 4 RMS value: 0.2697
Mic 4 Peak value: 0.55817

Mic 4: +++++++ PASSED +++++++

Enter Mic Number & press 'Enter' to test mic 5: 14
Testing mic 5
Mic 5 RMS value: 0.2484
Mic 5 Peak value: 0.51788

Mic 5: ------- FAILED -------

Enter Mic Number & press 'Enter' to test mic 6: 30
Testing mic 6
Mic 6 RMS value: 0.31312
Mic 6 Peak value: 0.64975

Mic 6: +++++++ PASSED +++++++

Enter Mic Number & press 'Enter' to test mic 7: 36
Testing mic 7
Mic 7 RMS value: 0.31013
Mic 7 Peak value: 0.65131

Mic 7: +++++++ PASSED +++++++

Enter Mic Number & press 'Enter' to test mic 8: 24
Testing mic 8
Mic 8 RMS value: 0.37688
Mic 8 Peak value: 0.78378

Mic 8: ------- FAILED -------

Enter Mic Number & press 'Enter' to test mic 1: 2
Testing mic 1
Mic 1 RMS value: 0.27449
Mic 1 Peak value: 0.65216

Mic 1: +++++++ PASSED +++++++

Enter Mic Number & press 'Enter' to test mic 2: 35
Testing mic 2
Mic 2 RMS value: 0.14223
Mic 2 Peak value: 0.99997

Mic 2: ------- FAILED -------

Enter Mic Number & press 'Enter' to test mic 3: 10
Testing mic 3
Mic 3 RMS value: 0.28091
Mic 3 Peak value: 0.58881

Mic 3: +++++++ PASSED +++++++

Enter Mic Number & press 'Enter' to test mic 4: 32
Testing mic 4
Mic 4 RMS value: 0.22254
Mic 4 Peak value: 0.47183

Mic 4: ------- FAILED -------

Enter Mic Number & press 'Enter' to test mic 5: 18
Testing mic 5
Mic 5 RMS value: 0.32016
Mic 5 Peak value: 0.67023

Mic 5: ------- FAILED -------

Enter Mic Number & press 'Enter' to test mic 6: 46
Testing mic 6
Mic 6 RMS value: 0.31007
Mic 6 Peak value: 0.64877

Mic 6: +++++++ PASSED +++++++

Enter Mic Number & press 'Enter' to test mic 7: 31
Testing mic 7
Mic 7 RMS value: 0.23287
Mic 7 Peak value: 0.49838

Mic 7: ------- FAILED -------

Enter Mic Number & press 'Enter' to test mic 8: 50
Testing mic 8
Mic 8 RMS value: 0.22932
Mic 8 Peak value: 0.4986

Mic 8: ------- FAILED -------

Enter Mic Number & press 'Enter' to test mic 1: 29
Testing mic 1
Mic 1 RMS value: 0.25957
Mic 1 Peak value: 0.59473

Mic 1: +++++++ PASSED +++++++

Enter Mic Number & press 'Enter' to test mic 2: 40
Testing mic 2
Mic 2 RMS value: 0.29142
Mic 2 Peak value: 0.59915

Mic 2: +++++++ PASSED +++++++

Enter Mic Number & press 'Enter' to test mic 3: 64
Testing mic 3
Mic 3 RMS value: 0.26319
Mic 3 Peak value: 0.55518

Mic 3: +++++++ PASSED +++++++

Enter Mic Number & press 'Enter' to test mic 4: 39
Testing mic 4
Mic 4 RMS value: 0.22534
Mic 4 Peak value: 0.47797

Mic 4: ------- FAILED -------

Enter Mic Number & press 'Enter' to test mic 5: 63
Testing mic 5
Mic 5 RMS value: 0.31744
Mic 5 Peak value: 0.66757

Mic 5: +++++++ PASSED +++++++

Enter Mic Number & press 'Enter' to test mic 6: 54
Testing mic 6
Mic 6 RMS value: 0.30674
Mic 6 Peak value: 0.66196

Mic 6: +++++++ PASSED +++++++

Enter Mic Number & press 'Enter' to test mic 7: 22
Testing mic 7
Mic 7 RMS value: 0.26108
Mic 7 Peak value: 0.55832

Mic 7: +++++++ PASSED +++++++

Enter Mic Number & press 'Enter' to test mic 8: 41
Testing mic 8
Mic 8 RMS value: 0.28246
Mic 8 Peak value: 0.58978

Mic 8: +++++++ PASSED +++++++

Enter Mic Number & press 'Enter' to test mic 1: 
Testing mic 1
Mic 1 RMS value: 0.10297
Mic 1 Peak value: 0.99997

Mic 1: ------- FAILED -------

Enter Mic Number & press 'Enter' to test mic 2: 70
Testing mic 2
Mic 2 RMS value: 0.31719
Mic 2 Peak value: 0.66364

Mic 2: +++++++ PASSED +++++++

Enter Mic Number & press 'Enter' to test mic 3: 16
Testing mic 3
Mic 3 RMS value: 0.355
Mic 3 Peak value: 0.73383

Mic 3: ------- FAILED -------

Enter Mic Number & press 'Enter' to test mic 4: 68
Testing mic 4
Mic 4 RMS value: 0.27761
Mic 4 Peak value: 0.58627

Mic 4: +++++++ PASSED +++++++

Enter Mic Number & press 'Enter' to test mic 5: 69
Testing mic 5
Mic 5 RMS value: 0.27874
Mic 5 Peak value: 0.58105

Mic 5: +++++++ PASSED +++++++

Enter Mic Number & press 'Enter' to test mic 6: 66
Testing mic 6
Mic 6 RMS value: 0.26748
Mic 6 Peak value: 0.5607

Mic 6: +++++++ PASSED +++++++

Enter Mic Number & press 'Enter' to test mic 7: 67
Testing mic 7
Mic 7 RMS value: 0.26825
Mic 7 Peak value: 0.56384

Mic 7: +++++++ PASSED +++++++

Enter Mic Number & press 'Enter' to test mic 8: 72
Testing mic 8
Mic 8 RMS value: 0.27391
Mic 8 Peak value: 0.57681

Mic 8: +++++++ PASSED +++++++

Enter Mic Number & press 'Enter' to test mic 1: 35
Testing mic 1
Mic 1 RMS value: 0.2793
Mic 1 Peak value: 0.57874

Mic 1: +++++++ PASSED +++++++

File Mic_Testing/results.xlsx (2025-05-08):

status | mics | test 1 | test 2 | test 3 | test 4 | test 5 | mean | std |  |  | global mean | global std
fail | 1 | 0.22421 | 0.14403 | 0.27903 |  |  | 0.1841 | 0.0567 |  |  | 0.2773 | 0.0437
PASS | 2 | 0.27449 | 0.35559 | 0.18379 |  |  | 0.3150 | 0.0573
PASS | 3 | 0.24069 | 0.28545 | 0.29007 |  |  | 0.2631 | 0.0317
PASS | 4 | 0.27863 | 0.23326 | 0.25001 |  |  | 0.2559 | 0.0321
PASS | 5 | 0.28536 | 0.27177 | 0.29205 |  |  | 0.2786 | 0.0096
fail | 6 | 0.27868 | 0.18622 | 0.30534 |  |  | 0.2324 | 0.0654
PASS | 7 | 0.26876 | 0.29181 | 0.26163 |  |  | 0.2803 | 0.0163
PASS | 8 | 0.29352 | 0.23421 | 0.27672 |  |  | 0.2639 | 0.0419 | # Pass | 50
fail | 9 | 0.33212 | 0.32278 | 0.30184 |  |  | 0.3275 | 0.0066
PASS | 10 | 0.28091 | 0.2645 | 0.33094 |  |  | 0.2727 | 0.0116
PASS | 11 | 0.27168 | 0.27681 | 0.2706 |  |  | 0.2742 | 0.0036
PASS | 12 | 0.32259 | 0.24757 | 0.23714 |  |  | 0.2851 | 0.0530
fail | 13 | 0.24467 | 0.21599 | 0.26584 |  |  | 0.2303 | 0.0203
PASS | 14 | 0.28608 | 0.26397 | 0.29708 |  |  | 0.2750 | 0.0156
PASS | 15 | 0.2484 | 0.26847 | 0.30182 |  |  | 0.2584 | 0.0142
PASS | 16 | 0.355 | 0.25025 | 0.29999 |  |  | 0.3026 | 0.0741
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

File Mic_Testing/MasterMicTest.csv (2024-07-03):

Channel | Status | RMS | Peak |  | RMS Mean | RMS STD | RMS Var | Peak Mean | Peak STD | Peak Var
Ch1 | PASSED | 0.28711 | 0.59238 |  | 0.2867 | 0.0326 | 0.00106 | 0.5906 | 0.5906 | 0.5906
Ch2 | PASSED | 0.26958 | 0.56735
Ch3 | PASSED | 0.30729 | 0.62552
Ch4 | PASSED | 0.33984 | 0.69119
Ch5 | PASSED | 0.28741 | 0.58841
Ch6 | PASSED | 0.29788 | 0.60812
Ch7 | PASSED | 0.26891 | 0.54822 |  | # std range | 41
Ch8 | PASSED | 0.34686 | 0.71878
Ch1 | PASSED | 0.27097 | 0.56885 |  | need | 48
Ch2 | PASSED | 0.28806 | 0.58829
Ch3 | PASSED | 0.32044 | 0.65836
Ch4 | PASSED | 0.31457 | 0.64365
Ch5 | PASSED | 0.29873 | 0.61267
Ch6 | PASSED | 0.25176 | 0.5137
Ch7 | PASSED | 0.34808 | 0.71255
Ch8 | PASSED | 0.28075 | 0.5715
Ch1 | PASSED | 0.22576 | 0.47137
Ch2 | PASSED | 0.27701 | 0.56665
Ch3 | PASSED | 0.25835 | 0.52731
Ch4 | PASSED | 0.28734 | 0.58551
Ch5 | PASSED | 0.30704 | 0.63809
Ch6 | PASSED | 0.33528 | 0.68658
Ch7 | PASSED | 0.26442 | 0.5488
Ch8 | PASSED | 0.2825 | 0.57602
Ch1 | PASSED | 0.29658 | 0.60901
Ch2 | PASSED | 0.32375 | 0.65958
Ch3 | PASSED | 0.28547 | 0.58392
Ch4 | PASSED | 0.32409 | 0.65768
Ch5 | PASSED | 0.33462 | 0.71948
Ch6 | PASSED | 0.30663 | 0.62799
Ch7 | FAILED |  |  | 0.09425 | 0.19208
Ch8 | PASSED | 0.25784 | 0.53058
Ch1 | PASSED | 0.27243 | 0.5632
Ch2 | PASSED | 0.32014 | 0.65289
Ch3 | PASSED | 0.21955 | 0.46167
Ch4 | PASSED | 0.24583 | 0.50113
Ch5 | PASSED | 0.24145 | 0.49768
Ch6 | PASSED | 0.25817 | 0.53177
Ch7 | PASSED | 0.27368 | 0.56934
Ch8 | PASSED | 0.37215 | 0.76025
Ch1 | PASSED | 0.29245 | 0.60062
Ch2 | PASSED | 0.27967 | 0.57553
Ch3 | PASSED | 0.30479 | 0.64261
Ch4 | PASSED | 0.26799 | 0.54996
Ch5 | PASSED | 0.26379 | 0.55414
Ch6 | PASSED | 0.23402 | 0.48724
Ch7 | PASSED | 0.27034 | 0.55588
Ch8 | PASSED | 0.30366 | 0.62634
Ch1 | PASSED | 0.27236 | 0.56836
Ch2 | PASSED | 0.24679 | 0.50659
Ch3 | PASSED | 0.2952 | 0.60464
Ch4 | PASSED | 0.28628 | 0.58353
Ch5 | PASSED | 0.25327 | 0.52548
Ch6 | PASSED | 0.24193 | 0.50232
Ch7 | PASSED | 0.22921 | 0.46762
Ch8 | PASSED | 0.31868 | 0.65375
Ch1 | PASSED | 0.2671 | 0.55716
Ch2 | PASSED | 0.27331 | 0.56674
Ch3 | PASSED | 0.3393 | 0.69107
Ch4 | PASSED | 0.32221 | 0.65576
Ch5 | PASSED | 0.27693 | 0.5704
Ch6 | PASSED | 0.31218 | 0.66202
Ch7 | PASSED | 0.26564 | 0.54715
Ch8 | PASSED | 0.29863 | 0.61728

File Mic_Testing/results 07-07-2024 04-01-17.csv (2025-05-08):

Channel | Status | RMS | Peak | MicNum
Ch1 | PASSED | 0.29064 | 0.61392 | 35
Ch2 | PASSED | 0.31369 | 0.64697 | 70
Ch3 | FAILED | 0.25025 | 0.54694 | 16
Ch4 | FAILED | 0.20729 | 0.43298 | 68
Ch5 | PASSED | 0.28109 | 0.57831 | 69
Ch6 | PASSED | 0.28427 | 0.59366 | 66
Ch7 | PASSED | 0.29197 | 0.61893 | 67
Ch8 | PASSED | 0.27719 | 0.5766 | 72
Ch9 | PASSED | 0.31904 | 0.6647 | 63
Ch10 | PASSED | 0.27681 | 0.57837 | 11
Ch11 | FAILED | 0.34319 | 0.72116 | 49
Ch12 | FAILED | 0.24757 | 0.51678 | 12
Ch13 | PASSED | 0.26409 | 0.55621 | 61
Ch14 | FAILED | 0.32278 | 0.68268 | 9
Ch15 | FAILED | 0.32316 | 0.68771 | 55
Ch16 | PASSED | 0.29181 | 0.61337 | 7
Ch17 | PASSED | 0.2765 | 0.58295 | 59
Ch18 | FAILED | 0.37419 | 0.76981 | 30
Ch19 | FAILED | 0.00296 | 0.08267 | 6
Ch20 | PASSED | 0.3041 | 0.65311 | 29
Ch21 | PASSED | 0.28652 | 0.59317 | 44
Ch22 | PASSED | 0.30884 | 0.64246 | 17
Ch23 | PASSED | 0.29367 | 0.62811 | 64
Ch24 | PASSED | 0.29734 | 0.6156 | 54
Ch25 | PASSED | 0.31157 | 0.64774 | 65
Ch26 | FAILED | 0.23326 | 0.49313 | 4
Ch27 | FAILED | 0.25235 | 0.53662 | 48
Ch28 | FAILED | 0.19975 | 0.4158 | 32
Ch29 | FAILED | 0.35093 | 0.72281 | 34
Ch30 | PASSED | 0.29923 | 0.6304 | 19
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

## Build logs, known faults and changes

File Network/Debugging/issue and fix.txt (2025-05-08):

The issue was a race condition during boot where the Raspberry Pi’s USB-to-Ethernet adapters didn’t initialize in time, causing the br0 bridge to fail. This made the FPGA unreachable unless a manual SSH tunnel was used. The fix involved removing the static bridge declaration, disabling DHCP on the USB interfaces, and adding a systemd service that dynamically creates the bridge when the interfaces become available. This ensures reliable network setup regardless of device power-on order, eliminating the need for manual recovery steps.

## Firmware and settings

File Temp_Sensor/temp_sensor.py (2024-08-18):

import bme280
import smbus2
from time import sleep


port = 3
address = 0x76
bus = smbus2.SMBus(port)

bme280.load_calibration_params(bus,address)

while True:
    bme280_data = bme280.sample(bus,address)
    # date = bme280_data.timestamp.split(" ")[0]
    # time = bme280_data.timestamp.split(' ')[0].split('+')[0].split('.')[0] # need to correct time zone
    humidity  = int(bme280_data.humidity)
    ambient_temperature = int((bme280_data.temperature * 9/5) + 32)
    print(f'\tTemp: {ambient_temperature} F\t|\tHumid: {humidity} %')
    sleep(1)

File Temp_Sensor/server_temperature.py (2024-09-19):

from dataclasses import dataclass
import threading
import socket
import time
import bme280
import smbus2



def get_temp():
    port = 3
    address = 0x76
    bus = smbus2.SMBus(port)

    bme280.load_calibration_params(bus, address)

    bme280_data = bme280.sample(bus, address)
    # date = bme280_data.timestamp.split(" ")[0]
    # time = bme280_data.timestamp.split(' ')[0].split('+')[0].split('.')[0] # need to correct time zone
    # humidity = int(bme280_data.humidity)
    ambient_temperature = int((bme280_data.temperature * 9 / 5) + 32)
    bus.close()

    return ambient_temperature



class Server:
    def __init__(self, host='0.0.0.0', port=12345):
        self.host = host
        self.port = port
        self.socket = socket.socket(socket.AF_INET, socket.SOCK_STREAM)
        self.socket.setsockopt(socket.SOL_SOCKET, socket.SO_REUSEADDR, 1)
        self.socket.bind((self.host, self.port))
        self.socket.listen()
        self.running = False
        self.client_list = []
        self.controller = None
        self.hardware = None

        print(f"Server listening on {self.host}:{self.port}")


    def handle_client(self, client_socket):
        with client_socket:
            while True:
                data = client_socket.recv(1024)
                if not data:
                    break

                message = data.decode()

                if 'disconnecting' in message:
                    print('client disconnecting')

                elif 'temp_requested' in message:
                    air_temp = str(get_temp())
                    print(f'Air Temp: {air_temp}')
                    self.send_all(air_temp)

                else:
                    print('data not recognized')


    def run(self):
        self.running = True
        while self.running:
            try:
                client_socket, addr = self.socket.accept()
                print('client accepted')
                time.sleep(0.1)
                name = client_socket.recv(1024).decode()

                # check if client name already exists and remove them
                for client_x in self.client_list:
                    if client_x.name == name:
                        self.client_list.remove(client_x)

                client = Client(name=name, socket=client_socket, ip_addr=addr[0], port=addr[1])
                self.client_list.append(client)
                print(f"Connection from {client.name} with address: {addr}")
                client_socket.sendall('ack'.encode())
                threading.Thread(target=self.handle_client, args=(client_socket,), daemon=True).start()
            except Exception as e:
                print(f"Server error: {e}")


    def send_all(self, message):
        for client in self.client_list:
            try:
                # print(f'sending message: {message}')
                client.socket.sendall(message.encode())
            except Exception as e:
                print(f"Error sending message to {client.name}: {e}")


    def stop(self):
        self.send_all('server_disconnecting')
        print('Server Disconnected')
        self.running = False
        self.controller.server_running = False
        self.socket.close()
        self.client_list.clear()




@dataclass
class Client:
    name: str
    socket: object
    ip_addr: str
    port: int




# To run the server
if __name__ == '__main__':
    server = Server('0.0.0.0')
    server.run()

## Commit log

2024-05-24 characterization experiment initial commit
    [gain_defaults.csv, settings.csv]
2024-06-03 organizational updates
    [antenna_connector-B_Cu.gbr, antenna_connector-B_Mask.gbr, antenna_connector-B_Paste.gbr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]
2024-06-30 added sck, ws, and mic pins / removed enumerate from wire to data bus for sck / ws
2024-07-03 reorganized / rms ranges set / documentation
    [MasterMicTest.csv]
2024-07-11 added new parts
    [Parts.xlsx]
2024-07-13 organization and filters created
2024-07-25 fir filter work
2024-08-02 part additions
    [Parts.xlsx]
2024-08-10 added wireless access point code
2024-08-10 wireless connection troubleshooting
2024-08-14 remove wireless connection stuff for now
2024-08-16 added temp sensor config
2024-08-18 temp sensor updates
2024-08-18 temp sensor output
2024-08-18 uncommented temp sensor libs
2024-08-18 print server reply
2024-08-22 temp sensor
2024-08-23 temperature checking for FIR coeff regeneration
2024-08-28 work on the top middle frame
2024-08-28 template labels for bottom frames
2024-09-03 updating PCA detector frame template
2024-09-04 start button functionality, realtime bf, pro, pca
2024-09-05 calibration functions threads
2024-09-06 max anomaly button
2024-09-18 print air temp
2024-09-18 corrected run condition for requesting temp, removed debugging print statements
    [server_temperature.py]
2024-09-18 update thread placements
2024-09-18 check current states
2024-09-18 removed heartbeat stuff and redid connection issue
    [server_temperature.py]
2024-09-19 updated calibration conditions
2024-09-19 redid thread placement
2024-09-19 close bus for error prevention
    [server_temperature.py]
2024-09-29 mic antenna exoskeleton addition
    [exoskeleton.stp]
2025-05-08 application audio engine files created
    [results 07-07-2024 04-01-17.csv, results 07-08-2024 02-12-56.csv, results.xlsx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]
2025-05-12 updated middle frame structure to make room for heatmap
2025-05-12 added control over calibration time
2025-05-13 heatmap added but still some buggy things but works
2025-05-14 re partitioned top frame to add room for other controls. added clock feature
2025-05-14 viewing anomaly csv as a heatmap like from app
2025-05-14 attempt to create a quick backend flow for data already collected. calibration runs fine, but record is still slow but not sure why
2025-05-14 speed up queue time to get actual real time processing. attached phi from gui to gui input of beamformer
2025-05-14 saving heatmaps
2025-05-14 heatmap viewing updates
2025-05-14 heatmap saving debugging
2025-05-14 debugged final heatmap image
2025-05-15 experimenting with heatmap colors
2025-05-15 debugged updating number of output channels, bar chart visual, and heatmap labeling with grid
2025-05-15 added external play button and adjusted clock size
2025-05-15 external play button added / button logic started
2025-05-15 adjusted heatmap error and networking stuff
2025-05-16 added heatmap settings
2025-05-16 rasp pi temp sensor route config updated
2025-05-16 adjusted heatmap visual settings
2025-05-16 added ability to start app on different devices by adjusting the save directory stuff
2025-05-16 moved calibration timer condition to correct spot
2025-05-16 device specific file dialog box
2025-05-16 device specific file dialog
2025-05-16 external player listening options and added human operator mode button/window
2025-05-18 saving calibration files for loaded audio
2025-05-18 sleep for toggle button
2025-05-19 calibration parallel and new detector baseline loading
2025-05-20 started debugging calibration issues
2025-05-28 heatmap and detector additions / beginning of add server function
2025-05-31 gave controller entire app device instead of just string
2025-05-31 added heatmap filter settings frame
2025-05-31 added the generate full heatmap function
2025-05-31 updated devices settings to run with newly labeled app device
2025-05-31 move wind bias and edge suppression to heatmap
2025-05-31 attaching settings to controller, anomaly filter, saving heatmaps
2025-05-31 anomaly logging, calibration settings, etc
2025-06-01 classifier frame template
2025-06-01 added anomaly filter settings functionality and tried to debug global / local toggle settings
2025-06-02 settings log and temp readings during calibration fixes
